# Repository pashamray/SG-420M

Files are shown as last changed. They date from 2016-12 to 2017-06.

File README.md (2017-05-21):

# SG-420M

Прошивка модифицирована для работы с экранами на контроллере [HD44780](https://ru.wikipedia.org/wiki/HD44780), размером 16x2, такими как WH1602.
Подключение экрана аналогично подключению в частотомере [FC-510](http://leoniv.diod.club/projects/measuring/fc-510/fc-510.html)

#### Общий вид генератора

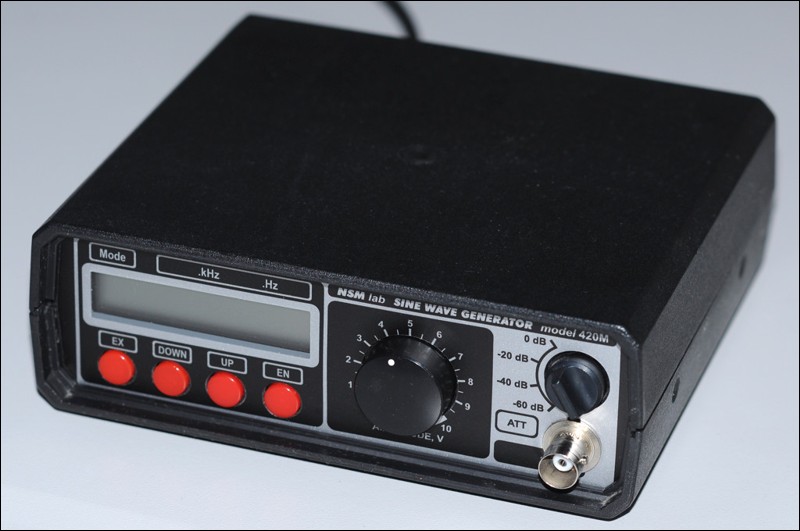
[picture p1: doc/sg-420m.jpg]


#### Вид лицевой панели

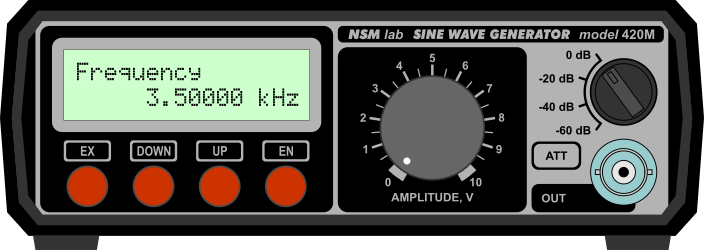
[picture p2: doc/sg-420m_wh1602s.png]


#### Схема подключения экрана

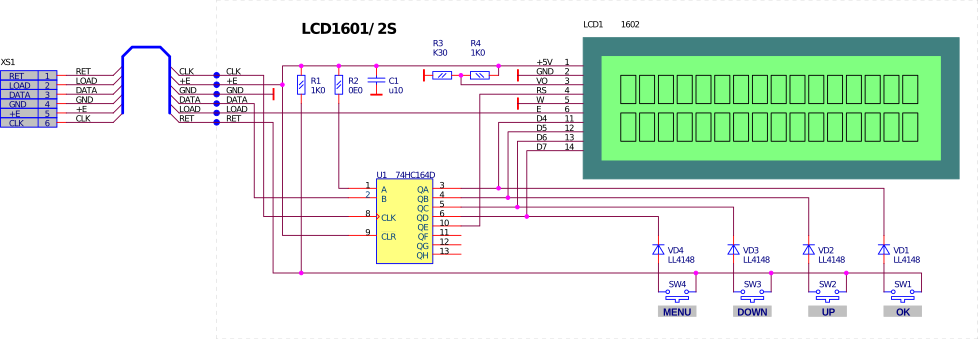
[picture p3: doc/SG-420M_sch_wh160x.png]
alt sch_wh1602s


#### Автор конструкций генератора и базовой прошивки

Ридико Леонид Иванович
* http://www.leoniv.diod.club
* http://leoniv.livejournal.com
* wubblick@yahoo.com

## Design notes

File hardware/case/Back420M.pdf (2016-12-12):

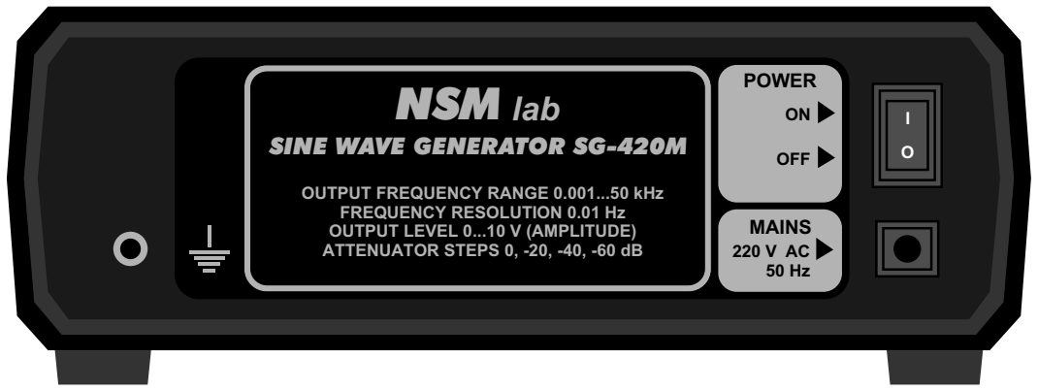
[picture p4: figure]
SINE WAVE GENERATOR SG-420M; NSM lab; OFF; POWER; MAINS; OUTPUT FREQUENCY RANGE 0.001...50 kHz FREQUENCY RESOLUTION 0.01 Hz OUTPUT LEVEL 0...10 V (AMPLITUDE) ATTENUATOR STEPS 0, -20, -40, -60 dB

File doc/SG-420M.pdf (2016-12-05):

NSMlab | wubblick@yahoo.com

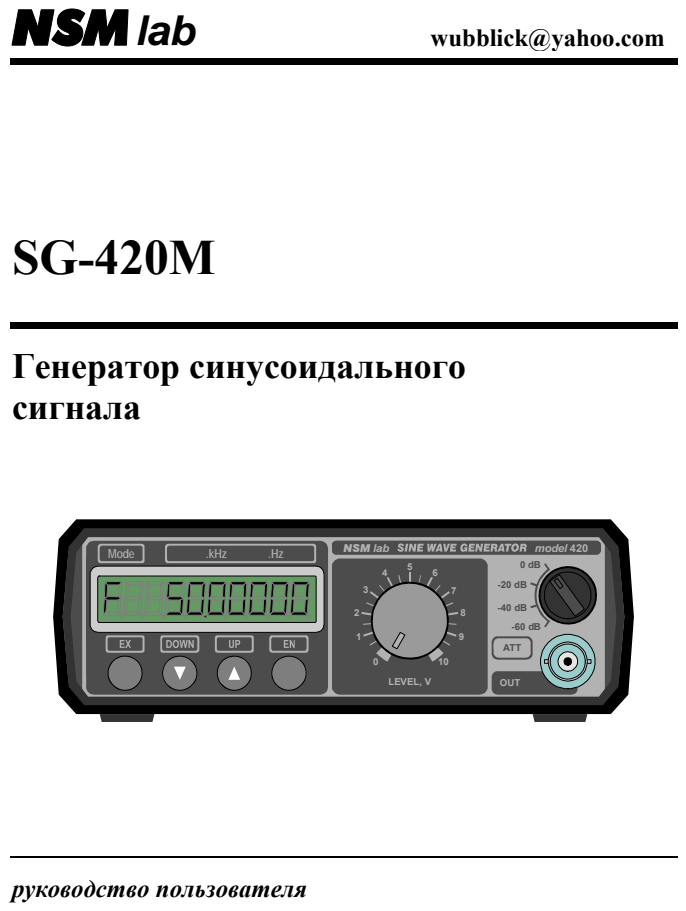
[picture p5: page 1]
Генератор синусоидального сигнала; model 420; OUT; ATT; LEVEL, V; NSM lab Mode; .kHz; руководство пользователя

SG-420M

- 2 -

ОСНОВНЫЕ ХАРАКТЕРИСТИКИ ГЕНЕРАТОРА
- диапазон генерируемых частот – 1…50000 Гц
- минимальный шаг установки частоты – 0.01 Гц
- среднеквадратическое выходное напряжение – 0…10 В
- пределы аттенюатора – 0, -20, -40, -60 дБ
- минимальное сопротивление нагрузки – 600 Ом
- коэффициент гармоник на частоте 1 КГц, не более – 0.01 %
- 10 предустановок частоты
- режим выключения сигнала
- цифровая калибровка частоты
- размеры – 150 x 130 x 50 мм
- вес – 0.4 кг

ОПИСАНИЕ ГЕНЕРАТОРА
Генератор построен на основе прямого цифрового синтезатора частоты (DDS, Direct Digital Synthesizer). Благодаря этому он имеет высокую стабильность выходной частоты, очень малый шаг перестройки и низкий коэффициент гармоник. Кроме того, генератор не имеет аномалий (переходных процессов) при перестройке частоты. Все это, вместе с малыми габаритами и весом, выгодно отличает данный генератор от обычных аналоговых генераторов.
DDS реализован программно на микроконтроллере ATmega8 фирмы "Atmel". Быстродействие этого контроллера является достаточным, чтобы при тактовой частоте 16 МГц реализовать 34-разрядный накопитель фазы, работающий на частоте 216 кГц. Такой накопитель фазы обеспечивает шаг перестройки частоты примерно 0.00001 Гц. Реально используется шаг сетки 0.01 Гц, что более чем достаточно на практике. В памяти микроконтроллера содержится таблица 1/4 периода синусоидального сигнала, адресуемая накопителем фазы. Формирование синусоидального напряжения производится с помощью
16-разрядного | ЦАП | TDA1543 | фирмы | "Philips". | Интерфейс | I²
S | эмулируется
микроконтроллером с помощью аппаратного модуля SPI и таймера. Для полного использования разрешающей способности ЦАП на промежутках между табличными отсчетами производится линейная интерполяция функции sin. Сформированный аналоговый сигнал подвергается низкочастотной фильтрации с помощью фильтра Баттерворта 4-го порядка. Отфильтрованный сигнал поступает на выходной каскад, который обеспечивает работу на нагрузку 600 Ом.
Основные органы управления генератора расположены на передней панели (рис. 1). Там же расположен выходной разъем типа BNC. На задней панели генератора расположены выключатель питания, сетевой шнур и клемма заземления.

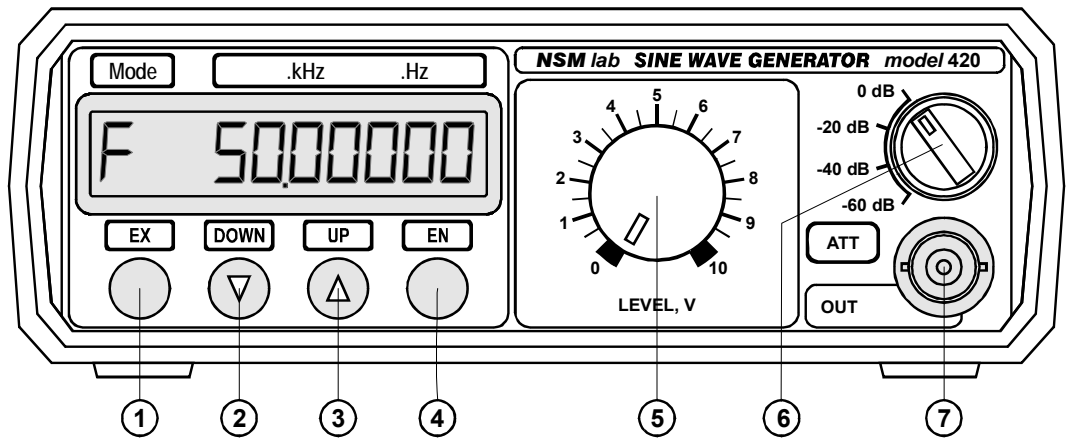
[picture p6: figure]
Mode; NSM lab; model 420; OUT; ATT; LEVEL, V; .kHz
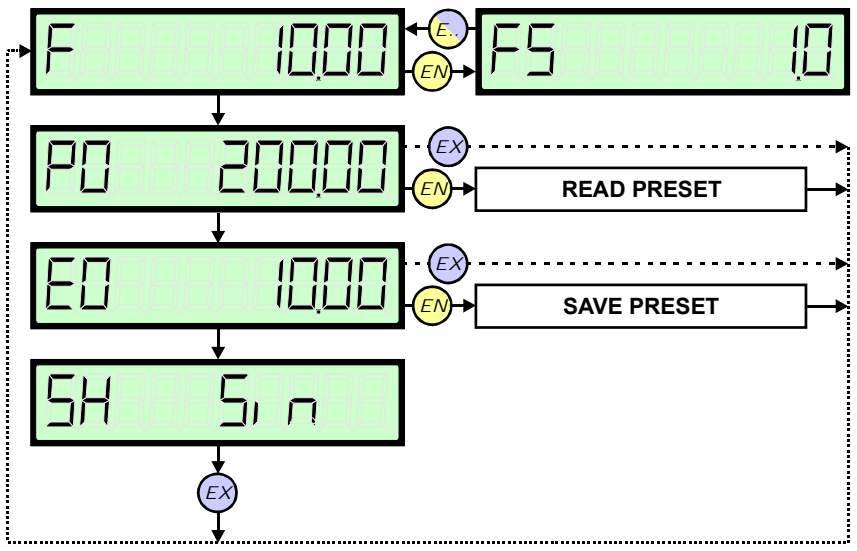
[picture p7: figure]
READ PRESET; SAVE PRESET

- 3 -

Рис. 1. Передняя панель генератора: 1 – кнопка EX (exit, выход); 2 – кнопка DOWN (меньше); 3 – кнопка UP (больше); 4 – кнопка EN (enter, ввод); 5 – ручка регулировки амплитуды выходного сигнала; 6 – ручка аттенюатора; 7 – выходной разъем.

УПРАВЛЕНИЕ ГЕНЕРАТОРОМ
Управление генератором осуществляется с помощью нескольких меню, которые выводятся на ЖКИ. Некоторые меню содержат цифровые значения параметров, другие меню позволяют выбрать нужный режим работы. Система меню организована в виде кольцевой структуры, кнопка EX (Exit) позволяет «по кругу» переходить между меню. Система меню генератора показана на рис. 2.

Рис. 2. Система меню генератора.

С помощью системы меню можно задать частоту выходного сигнала генератора, считать или записать предустановку частоты, а также выключить или включить выходной

- 4 -

сигнал. Увеличение или уменьшение значения выбранного параметра производится кнопками UP или DOWN соответственно. Значение частоты выводится с запятой, которая отделяет десятые доли герца, если значение меньше 1 КГц, или десятые доли килогерца, если значение больше 1 КГц. На рис. 3а показан пример индикации частоты, равной 10 Гц, а на рис. 3б – частоты 10 КГц.

а)

б)

Рис. 3. Пример индикации частоты выходного сигнала: 10 Гц (а) и 10 КГц (б).

Одиночное нажатие кнопки UP или DOWN приводит к изменению частоты на один шаг. Если кнопка продолжает удерживаться более 800 мс, то начинается автоповтор с периодом 180 мс. В таком режиме делается 16 шагов, затем включается быстрый автоповтор с периодом 60 мс.
Шаг изменения значения частоты задается в отдельном меню программирования шага (рис. 4) и может иметь значение 0.01 Гц…10 КГц.

Рис. 4. Меню программирования шага.

Войти в меню программирования шага можно из меню установки выходной частоты с помощью кнопки EN (Enter). Значение шага можно изменять с помощью кнопок UP и DOWN по закону 1-2-5-10-20-50-... и так далее. Выйти из меню программирования шага можно с помощью любой из кнопок EX или EN, при этом формируется специальный звуковой сигнал.
Значение частоты при редактировании с помощью кнопок UP и DOWN выравнивается на значение установленного шага. Например, если величина шага равна 1.00 Гц, текущая частота составляет 120.34 Гц и делается несколько шагов вверх, то получится следующая последовательность: 120.34 Гц, 121.00 Гц, 122.00 Гц и т.д. При перестройке вниз получится: 120.34 Гц, 120.00 Гц, 119.00 Гц и т.д. Поэтому если требуется установить какое-то нецелое значение частоты, нужно начинать с большого шага и заканчивать минимальным. Если текущее значение частоты меньше или равно величины шага, то при нажатии кнопки DOWN происходит автоматическое уменьшение шага по принятому для него закону, при этом раздается звуковой сигнал ошибки и на индикаторе кратковременно отображается то значение шага, которое вызвало ошибку.

- 5 -

ЧТЕНИЕ ПРЕДУСТАНОВОК ЧАСТОТЫ
Меню P (Read Preset) позволяет считать одну из десяти предустановок выходной частоты. При входе в это меню на индикаторе отображается символ P, а справа от него – номер предустановки. Номер может лежать в пределах от 0 до 9. Еще правее на индикаторе отображается значение частоты, сохраненное в данной предустановке. Номер предустановки можно изменять с помощью кнопок UP и DOWN. Чтобы ввести выбранную предустановку, нужно нажать кнопку EN. При этом генератор перестроится на частоту предустановки. Для того, чтобы отменить чтение предустановки, нужно нажать кнопку EX. В этом случае выходная частота останется неизменной, а генератор перейдет в режим установки частоты, если перед этим номер предустановки редактировался, или в меню сохранения предустановок, если номер не редактировался.

СОХРАНЕНИЕ ПРЕДУСТАНОВОК ЧАСТОТЫ
Меню E (Save Preset in EEPROM) позволяет запомнить до десяти значений выходной частоты генератора в виде предустановок. При входе в это меню на индикаторе отображается символ E, а справа от него – номер предустановки. Номер может лежать в пределах от 0 до 9. Еще правее на индикаторе отображается текущее значение выходной частоты генератора. Номер предустановки можно изменять с помощью кнопок UP и DOWN. Чтобы запомнить текущую частоту в выбранной предустановке, нужно нажать кнопку EN. При этом значение частоты сохраняется в EEPROM и формируется специальный звуковой сигнал. Для того, чтобы отменить сохранение предустановки, нужно нажать кнопку EX. В этом случае текущее значение частоты записано в EEPROM не будет, а генератор перейдет в режим установки частоты, если перед этим номер предустановки редактировался, или в меню формы выходного сигнала, если номер не редактировался.

ВЫКЛЮЧЕНИЕ ВЫХОДНОГО СИГНАЛА
Для выключения выходного сигнала генератора служит меню формы выходного сигнала SH (Shape). При входе в это меню на индикаторе отображаются символы SH, а справа от них – вид выходного сигнала. Вид сигнала может быть Sin – сигнал включен и OFF – сигнал выключен (рис. 5). Выключение и включение сигнала происходит с минимальным скачком фазы. Выключение происходит при изменении знака выходного напряжения с минуса на плюс, т.е. при переходе сигнала через ноль. Все время, пока выходной сигнал генератора выключен, на выходе поддерживается нулевое напряжение. При включении выходного синала его формирование начинается с нулевого значения фазы, т.е. с начала положительной полуволны.

а)

б)

Рис. 5. Меню формы выходного сигнала.

- 6 -

НАЧАЛЬНАЯ ЧАСТОТА ГЕНЕРАТОРА
Для того, чтобы при каждом включении питания генератора выходная частота принимала определенное значение, нужно сохранить это значение частоты в предустановке с номером 0. Предустановка 0 также используется для задания частоты, на которой будет производиться калибровка (см. ниже).

ЦИФРОВАЯ КАЛИБРОВКА
Поскольку DDS имеет очень малый шаг перестройки частоты (около 0.002 Гц), а реально используется шаг сетки 0.01 Гц, оказалось возможным осуществить цифровую калибровку частоты. Для калибровки нужно иметь эталонный частотомер или эталонный генератор. В первом случае добиваются нужных показаний частотомера, во втором – равенства частот.
Для осуществления калибровки сначала нужно задать частоту, на которой она будет проводиться. Для этого нужно установить желаемую частоту на выходе генератора и сохранить ее в предустановке с номером 0. Затем нужно войти в меню калибровки. Для этого необходимо выключить питание генератора, а затем включить его снова, удерживая нажатой кнопку EX. При таком включении генератор войдет в специальное меню калибровки. В этом меню на индикаторе отображается символ C и значение калибровочного коэффициента (рис. 6). Калибровочный коэффициент может принимать значения от 0.00 до 999.99. Номинальное значение коэффициента равно 500.00. Изменение значения калибровочного коэффициента на 1.00 соответствует изменению выходной частоты генератора примерно на 1 ppm (одну миллионную часть). Соответственно, с помощью процедуры калибровки можно изменить выходную частоту генератора не более, чем на ±500 ppm. Находясь в меню калибровки значение калибровочного коэффициента можно изменять с помощью кнопок UP и DOWN. Шаг изменения коэффициента равен 10, так как устанавливать выходную частоту до сотых долей ppm не имеет смысла. В процессе калибровки необходимо контролировать выходную частоту генератора, которая меняется при изменении калибровочного коэффициента.

Рис. 6. Меню калибровки.

Когда с помощью изменения значения калибровочного коэффициента требуемая выходная частота достигнута, необходимо сохранить новый калибровочный коэффициент. Для сохранения коэффициента нужно нажать кнопку EN. При этом новый коэффициент запишется в EEPROM, а генератор перейдет в режим установки частоты. Для того, чтобы отменить калибровку, нужно нажать кнопку EX. При этом восстановится прежнее значение калибровочного коэффициента, а генератор перейдет в режим установки частоты.
Если проводить калибровку генератора на частоте 15625.00 Гц, то в качестве эталонной частоты можно использовать строчную частоту телевизионного сигнала, принимаемого с эфира. Точность и стабильность этой частоты вполне достаточна для калибровки. Сравнение частот можно осуществить с помощью осциллографа по фигурам Лиссажу.

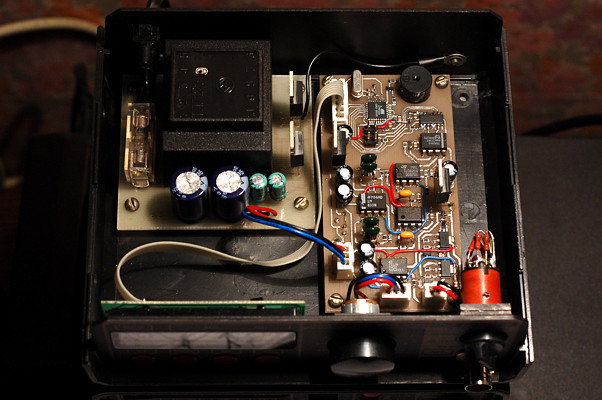
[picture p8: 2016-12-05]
doc/sg-420m_in.jpg

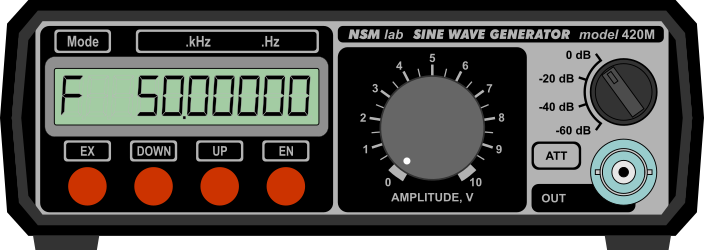
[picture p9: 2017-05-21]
doc/sg-420m_melt7.png

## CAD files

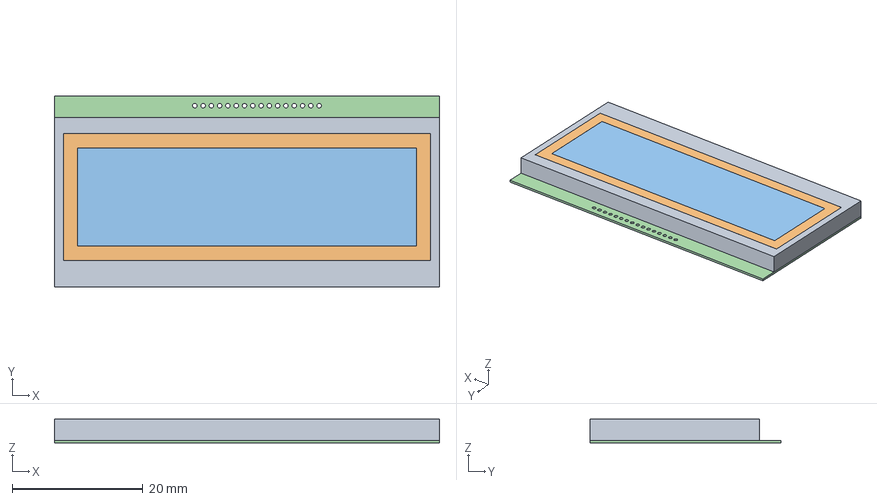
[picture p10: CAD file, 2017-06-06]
hardware/freecad/wh1602s.step
59.0 x 29.3 x 3.65 mm

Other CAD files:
hardware/freecad/wh1602s.fcstd

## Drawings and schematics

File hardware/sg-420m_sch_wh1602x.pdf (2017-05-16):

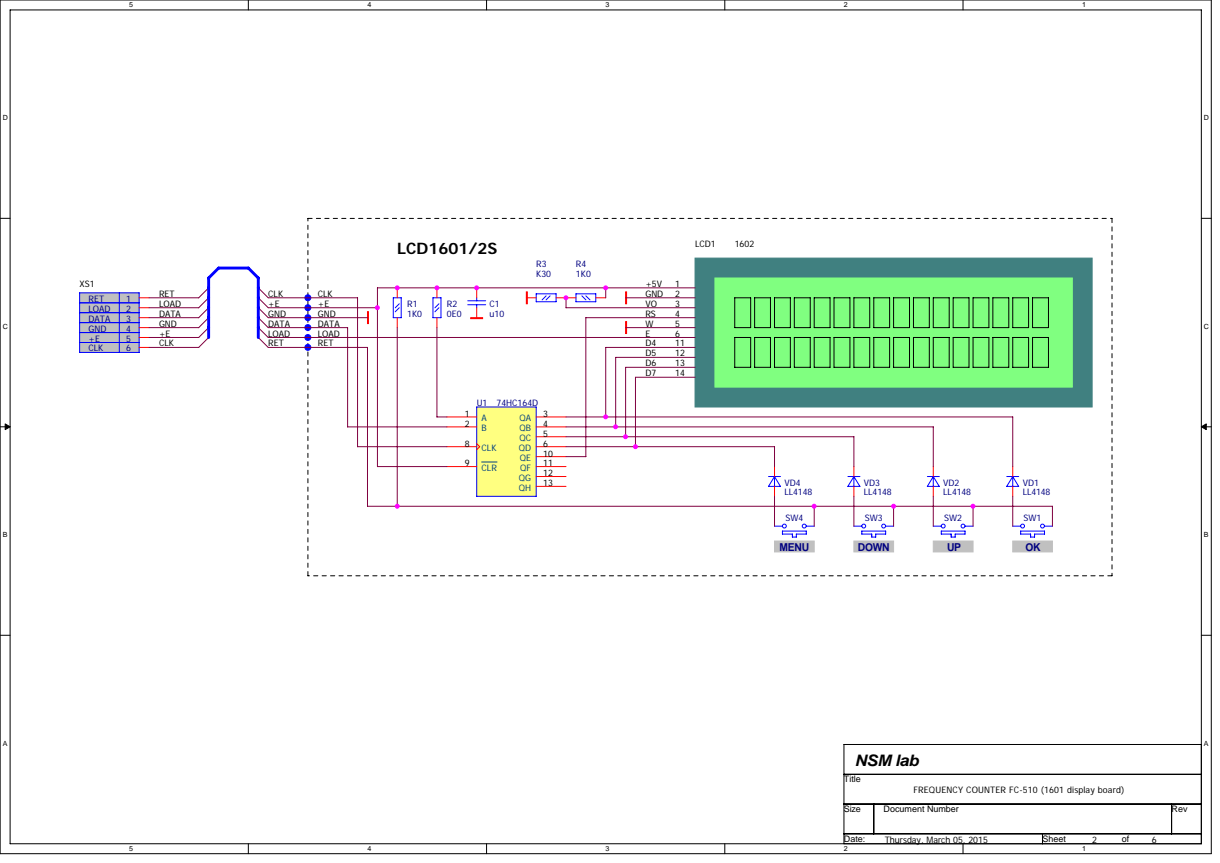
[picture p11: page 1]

RET | 1
LOAD | 2
DATA | 3
GND | 4
+E | 5
CLK | 6

10

FREQUENCY COUNTER FC-510 (1601 display board)

Size | Document Number | Rev

Date: Thursday, March 05, 2015 | Sheet of 2 6

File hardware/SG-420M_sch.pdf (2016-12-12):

# POWER SUPPLY

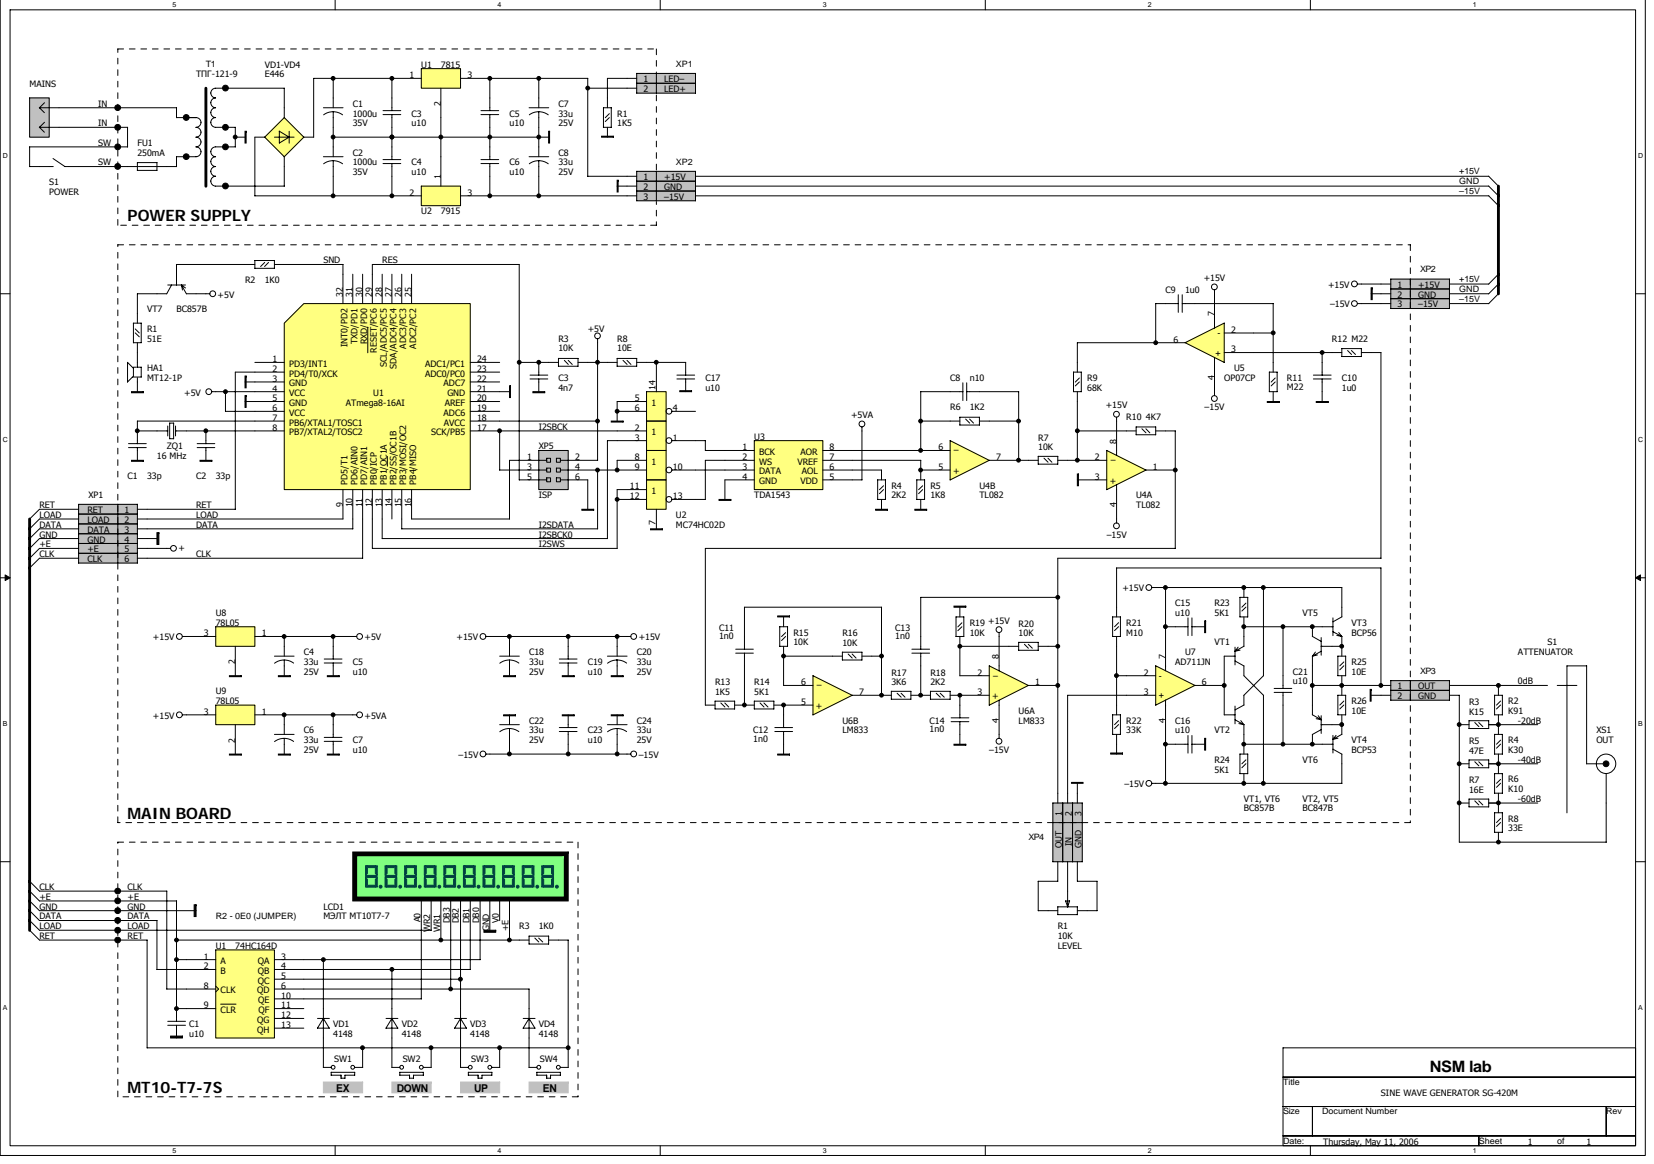
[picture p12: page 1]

1 | LED–
2 | LED+

1 | +15V
2 | GND
3 | –15V

RET | 1
LOAD | 2
DATA | 3
GND | 4
+E | 5
CLK | 6

1 | OUT

SINE WAVE GENERATOR SG-420M

Size | Document Number | Rev

Date: Thursday, May 11, 2006 | Sheet 1 of 1

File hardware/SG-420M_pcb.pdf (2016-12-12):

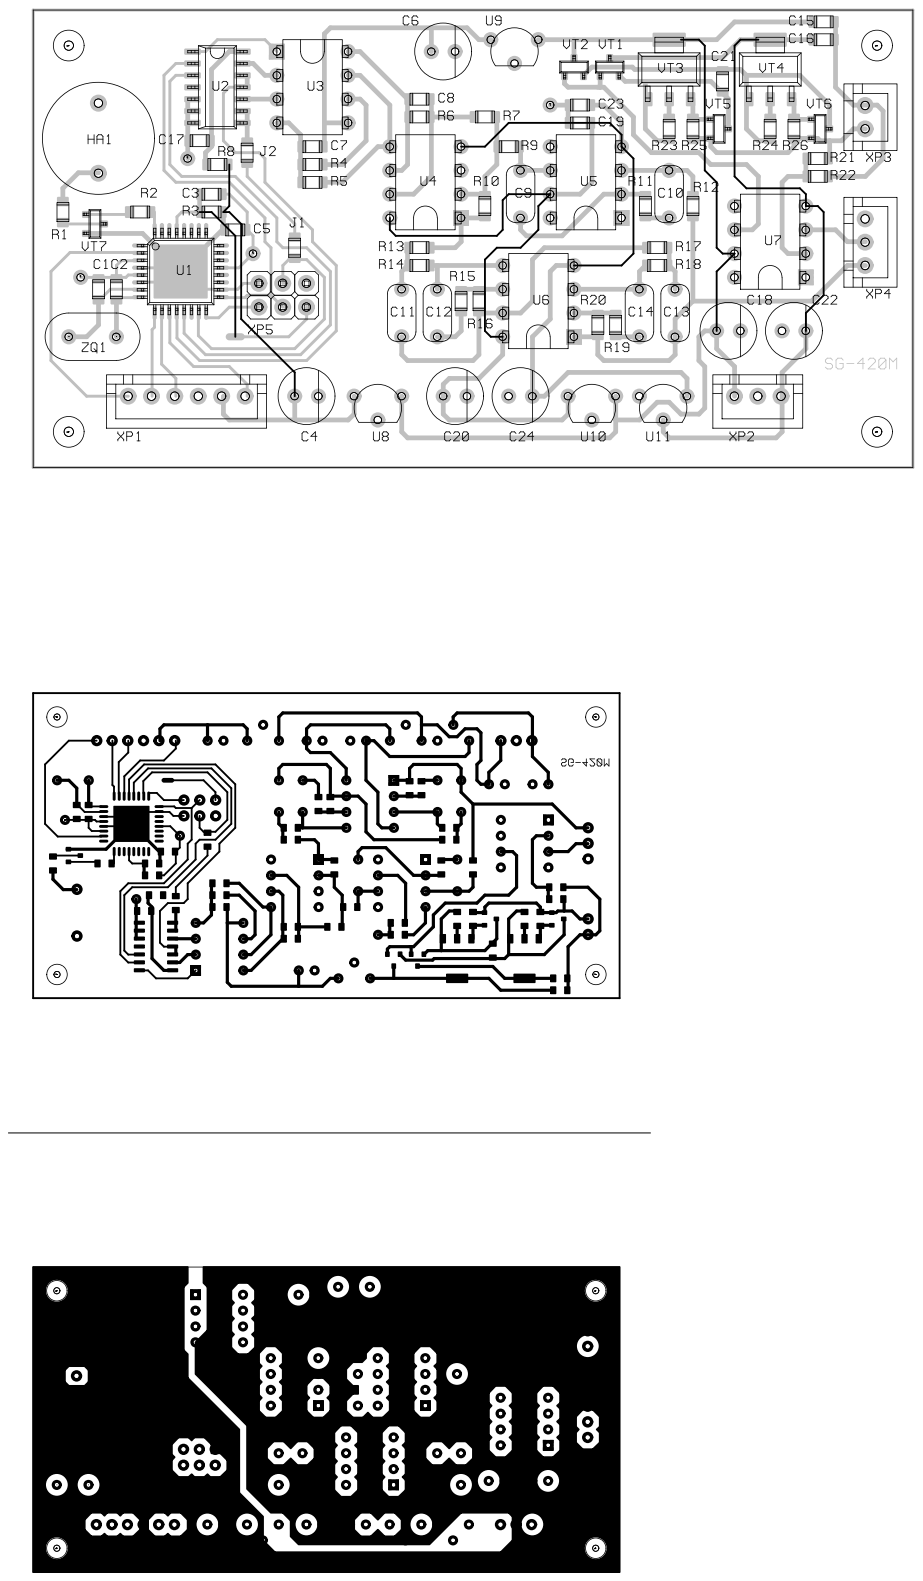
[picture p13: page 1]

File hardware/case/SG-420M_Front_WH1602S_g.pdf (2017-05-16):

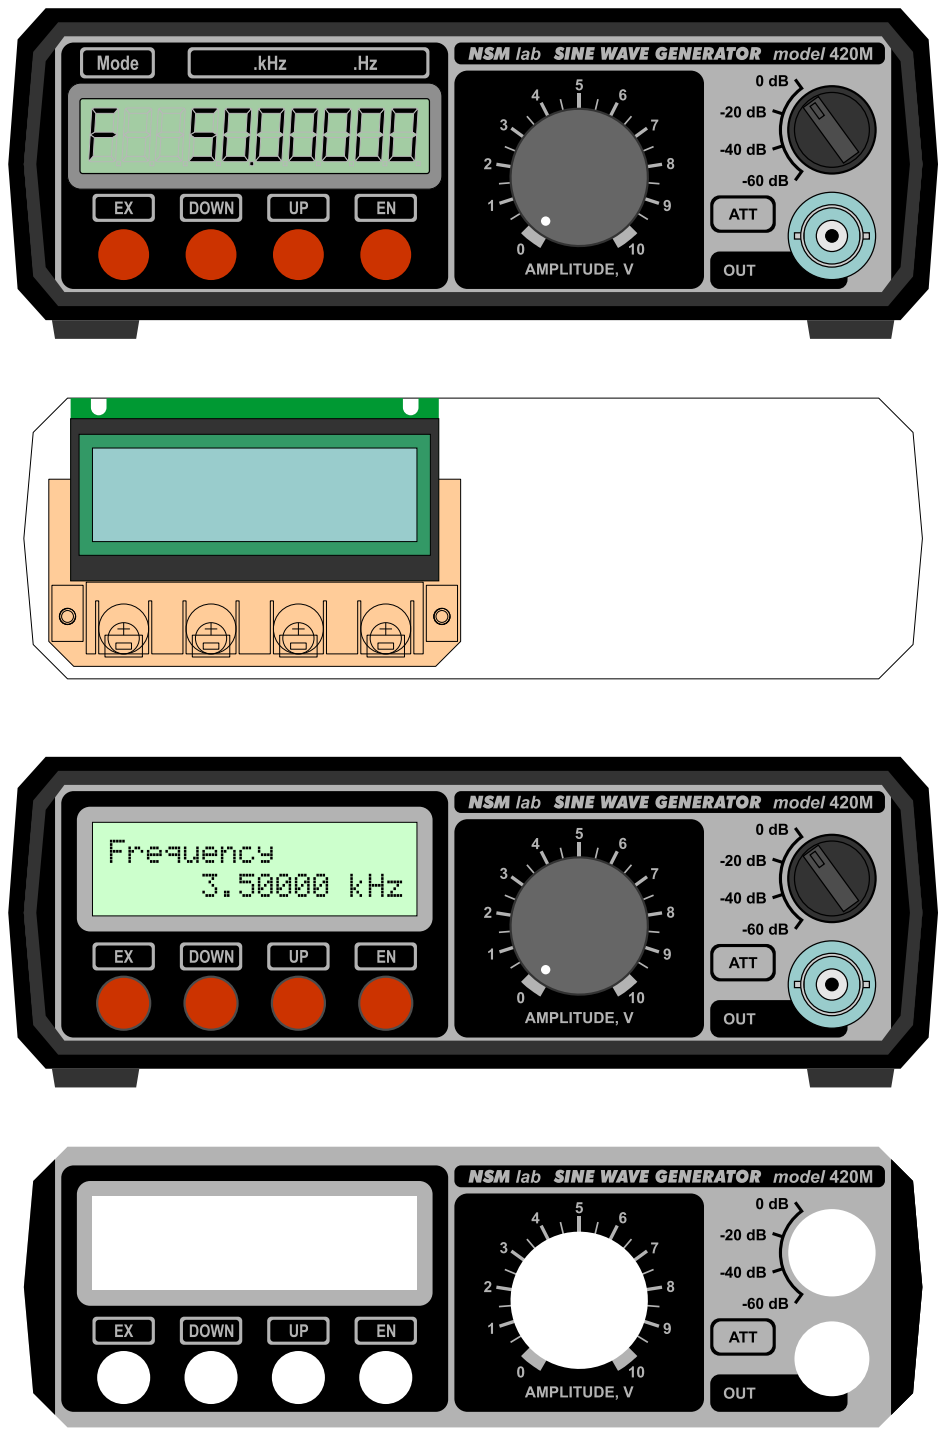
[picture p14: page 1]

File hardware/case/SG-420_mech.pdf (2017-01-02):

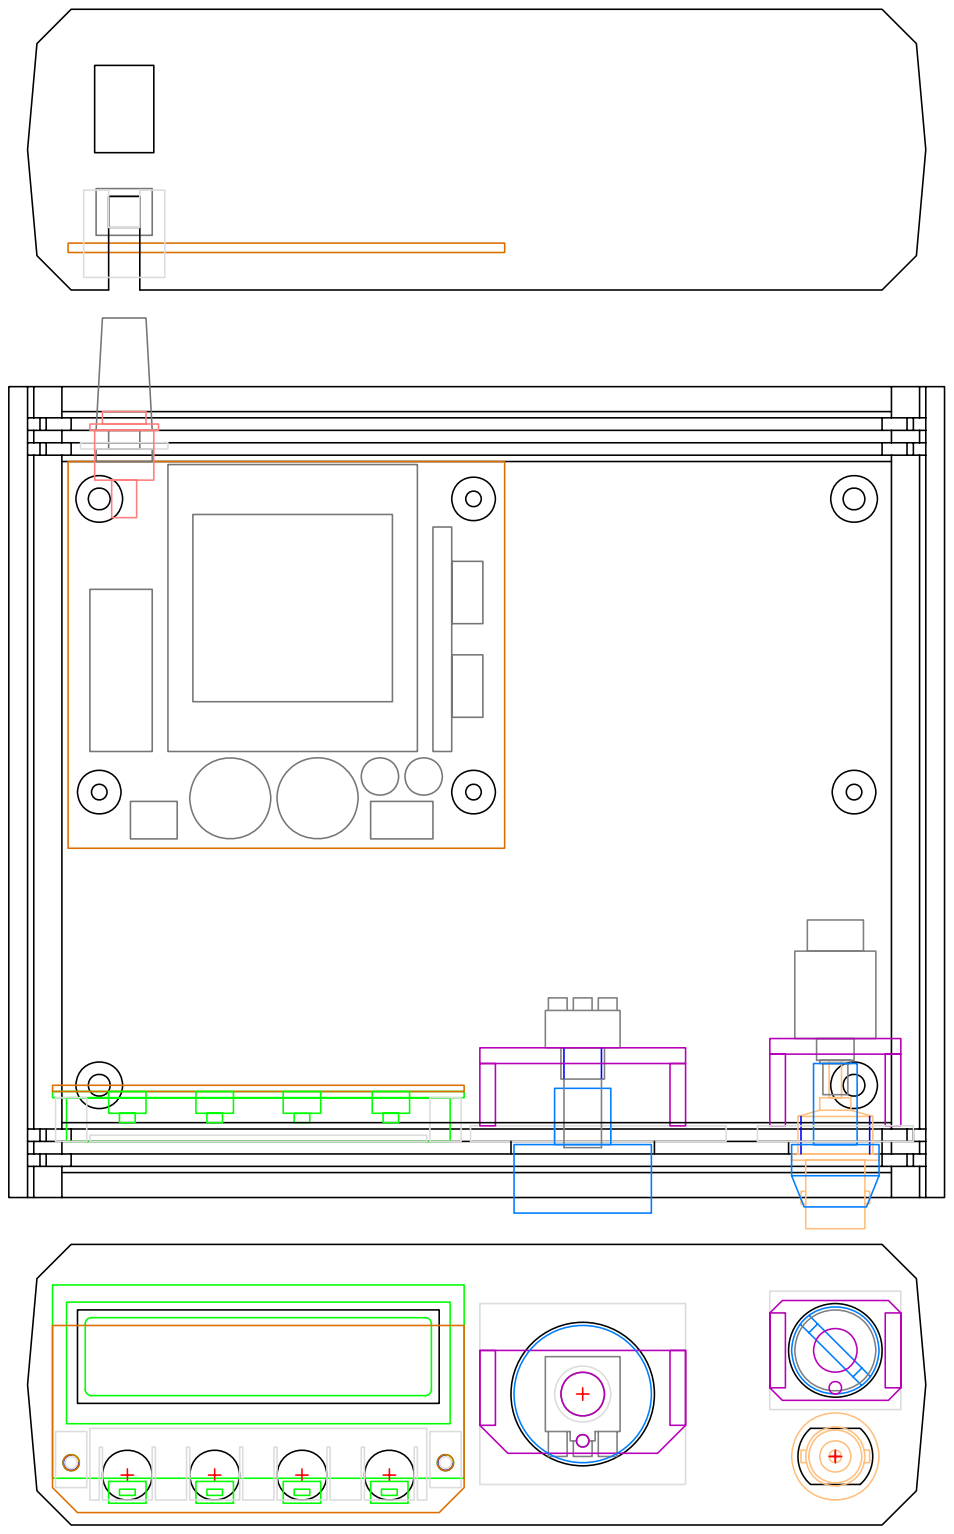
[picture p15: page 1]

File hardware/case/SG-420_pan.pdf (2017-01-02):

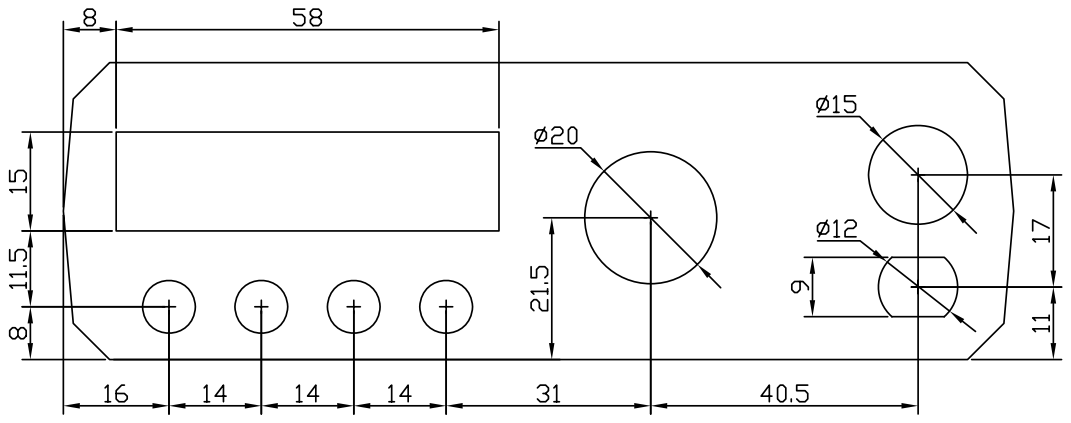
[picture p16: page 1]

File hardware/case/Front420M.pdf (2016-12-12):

# Mode .kHz .Hz

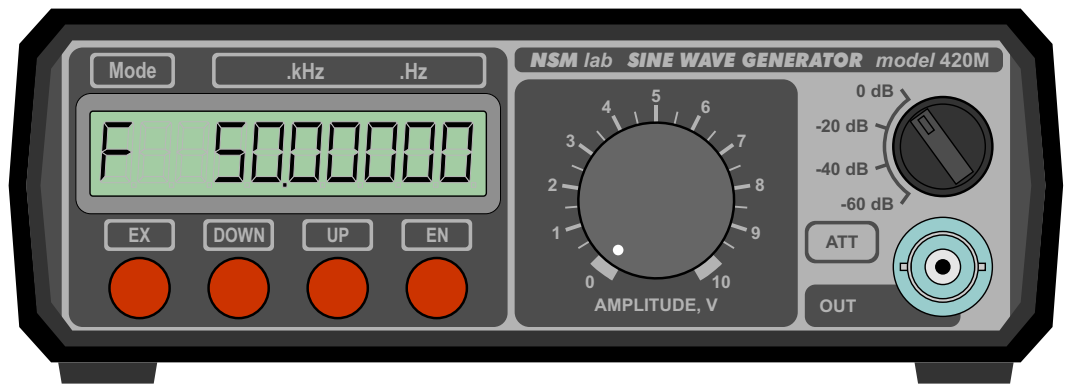
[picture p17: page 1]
DOWN; NSM lab SINE; WAVE GENERATOR model 420M; OUT; ATT; AMPLITUDE, V

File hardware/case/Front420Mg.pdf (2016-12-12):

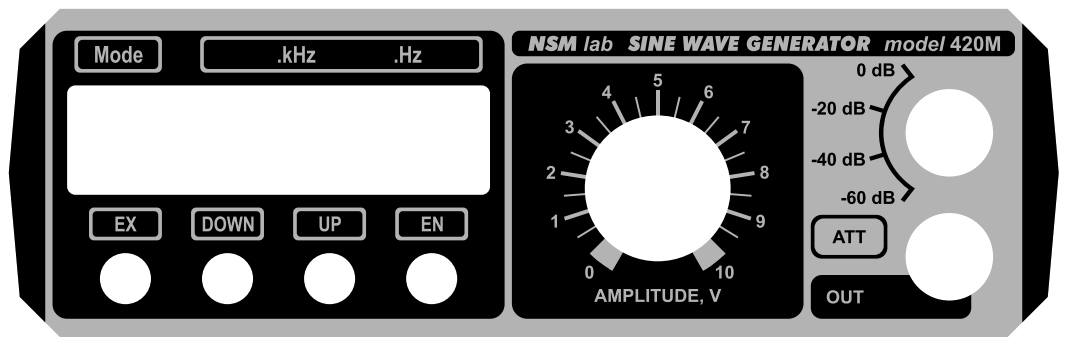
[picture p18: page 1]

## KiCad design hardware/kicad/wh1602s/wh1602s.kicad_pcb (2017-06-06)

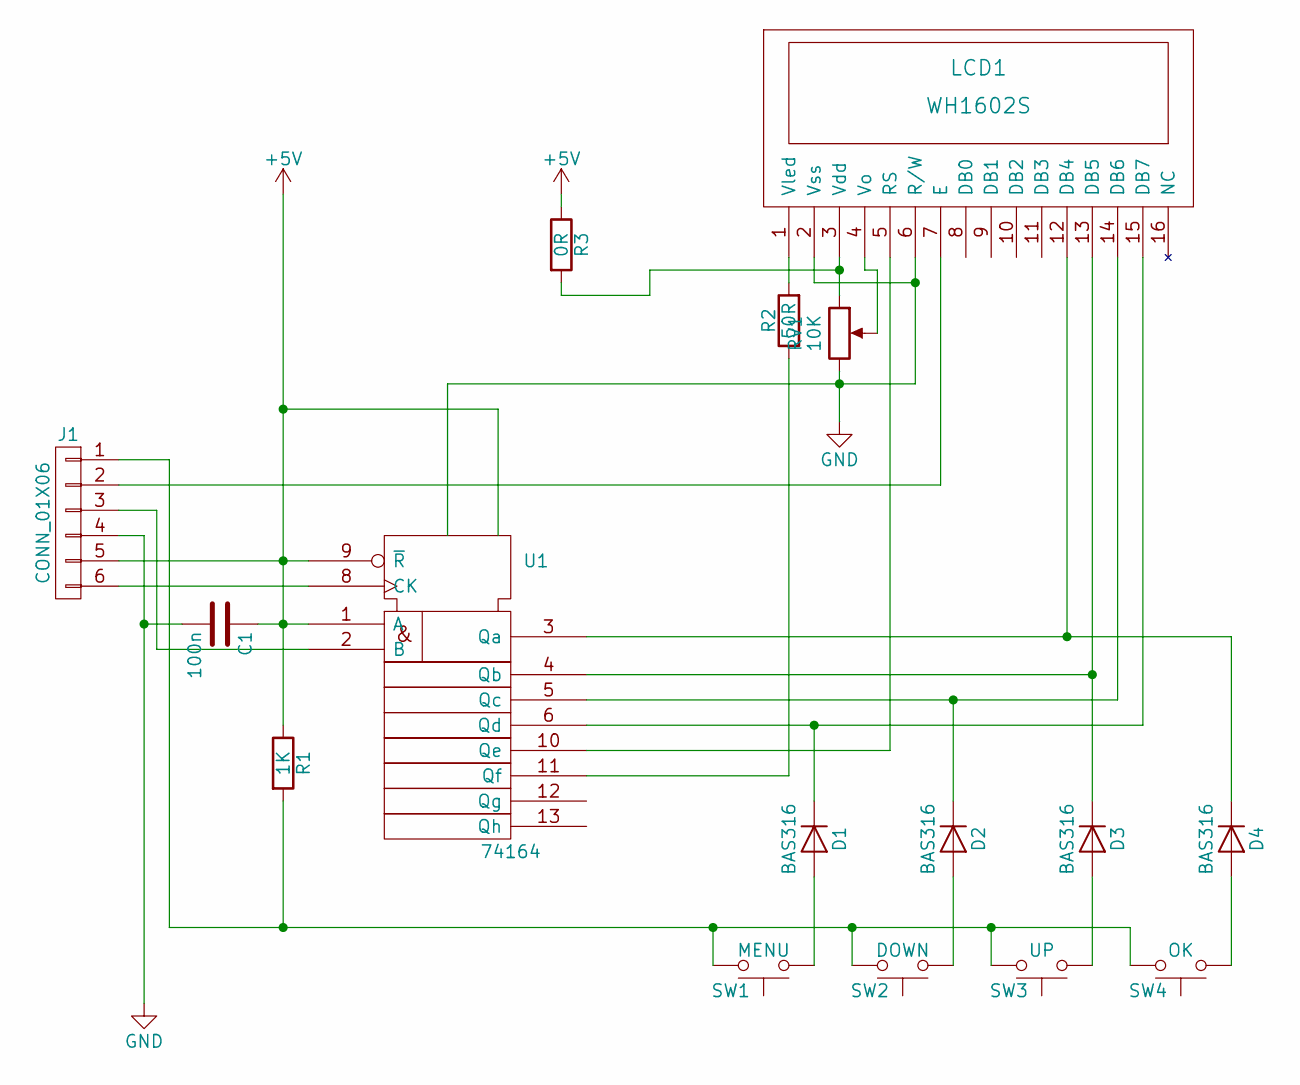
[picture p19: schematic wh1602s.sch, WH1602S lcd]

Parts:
C1: 100n; C_0805
D1, D2, D3, D4: BAS316; D_SOD-323
J1: CONN_01X06; Socket_Strip_Straight_1x06_Pitch2.54mm
LCD1: WH1602S
R1: 1K; R_0805
R2: 50R; R_0805
R3: 0R; R_0805
RV1: 10K; Potentiometer_Trimmer_Bourns_3296W
SW1: MENU; SW_PUSH-12mm
SW2: DOWN; SW_PUSH-12mm
SW3: UP; SW_PUSH-12mm
SW4: OK; SW_PUSH-12mm
U1: 74164; SOIC-14_N

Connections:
+5V: C1.1, J1.5, R1.1, R3.1, U1.1 (A), U1.9 (~R), U1.14 (Vdd)
GND: C1.2, J1.4, LCD1.2 (Vss), LCD1.6 (R/W), RV1.3, U1.7 (Vss)
unnamed: D1.1 (K), LCD1.15 (DB7), U1.6 (Qd)
unnamed: D1.2 (A), SW1.1
unnamed: D2.1 (K), LCD1.14 (DB6), U1.5 (Qc)
unnamed: D2.2 (A), SW2.1
unnamed: D3.1 (K), LCD1.13 (DB5), U1.4 (Qb)
unnamed: D3.2 (A), SW3.1
unnamed: D4.1 (K), LCD1.12 (DB4), U1.3 (Qa)
unnamed: D4.2 (A), SW4.1
unnamed: J1.1, R1.2, SW1.2, SW2.2, SW3.2, SW4.2
unnamed: J1.2, LCD1.7 (E)
unnamed: J1.3, U1.2 (B)
unnamed: J1.6, U1.8 (CK)
unnamed: LCD1.1 (Vled), R2.2
unnamed: LCD1.3 (Vdd), R3.2, RV1.1
unnamed: LCD1.4 (Vo), RV1.2
unnamed: LCD1.5 (RS), U1.10 (Qe)
unnamed: R2.1, U1.11 (Qf)

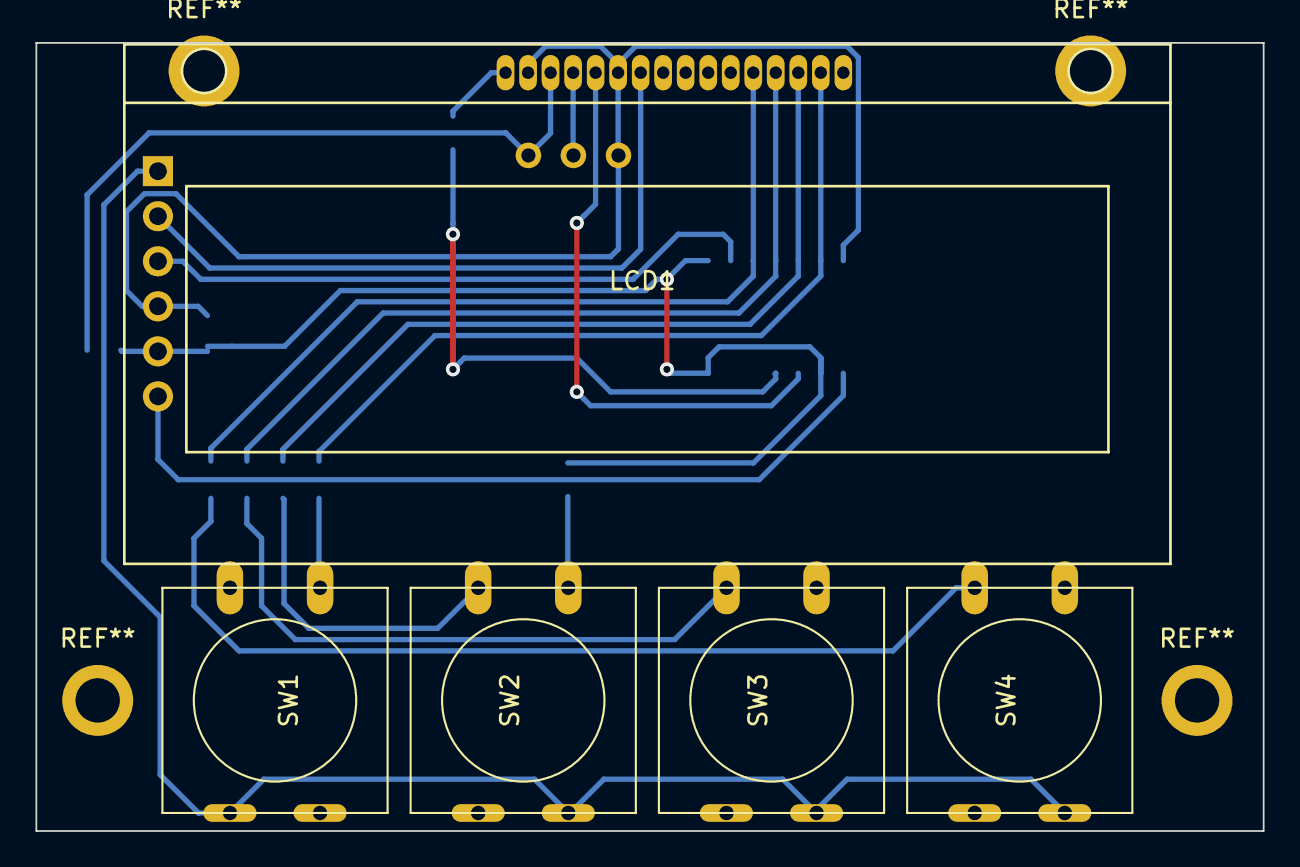
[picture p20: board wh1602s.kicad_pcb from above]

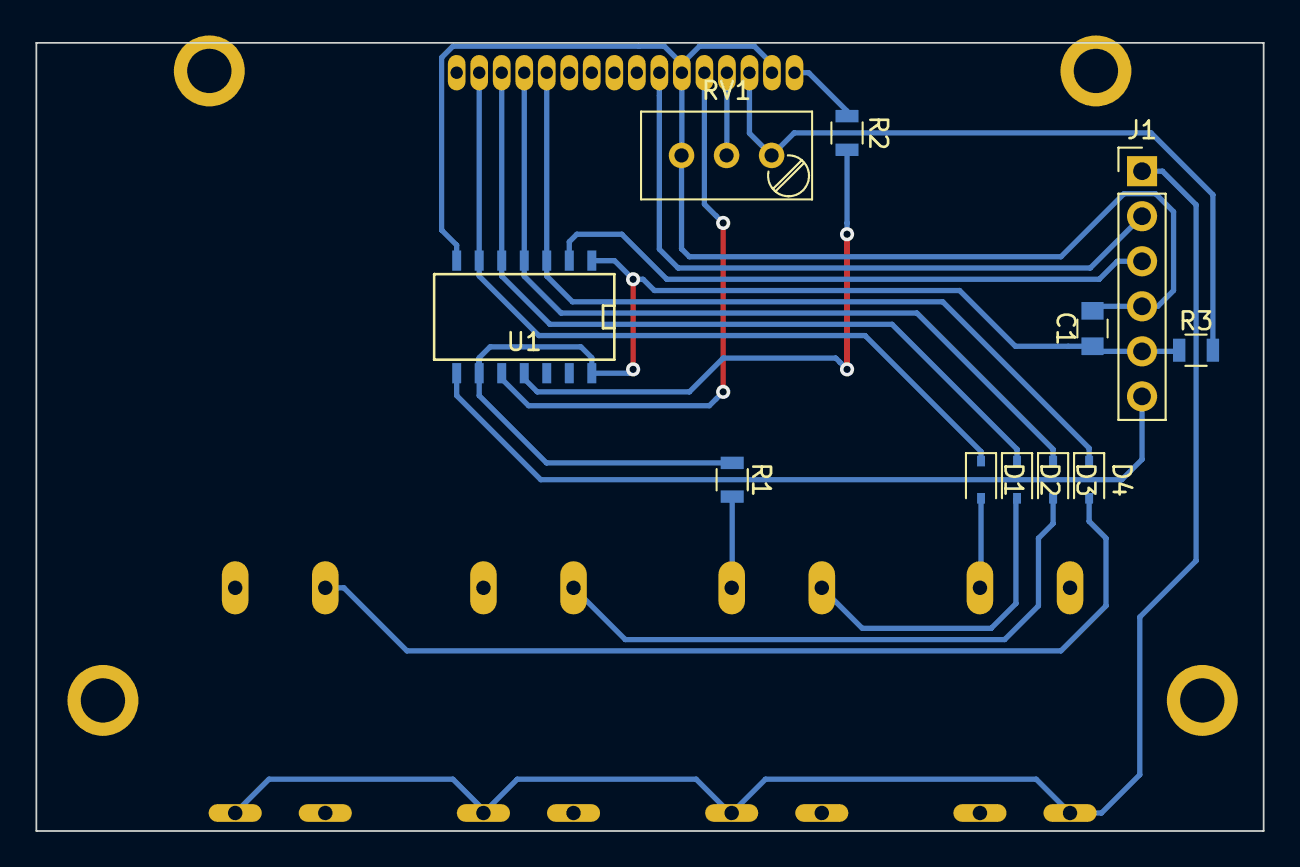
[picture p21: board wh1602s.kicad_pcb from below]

Board: 2 copper layers, 69.2 x 44.5 mm, 16 parts (11 on the bottom side), 19 nets.

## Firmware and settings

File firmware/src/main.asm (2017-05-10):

;----------------------------------------------------------------------------

;* Title	: SG-420M sine wave generator
;* Version	: 1.00
;* Target	: ATmega8
;* Author	: wubblick@yahoo.com

;----------------------------------------------------------------------------

.include "m8def.inc"
.include "macros.inc"
.include "header.asm"

;------------------------- Interrupt Vectors: -------------------------------

.CSEG				;code segment
.org	0
	rjmp	Init		;reset vector

.org	OC1Aaddr
.include "dds.asm"			;link DDS implementation module
							;DDS implementation is located direct at the OC1A vector address
							;Only one interrupt is used in this project

;--------------------------- Main program: ----------------------------------

Init:
	ldy		RAMEND
	out		SPL,YL		;locate stack
	out		SPH,YH
	rcall	iWdog		;start internal watchdog
	rcall	iPorts		;ports init
	rcall	iVar		;variables init
	rcall	iTimer		;system timer init
	rcall	iDisp		;LCD init
	rcall	iDDS		;DDS subsystem init
	sei					;enable interrupts
	rcall	iMenu		;menu subsystem init

;Main loop:

Main:
	rcall	mTimer		;process system timer
	rcall	mKey		;scan keyboard
	rcall	mMenu		;process menu
	rcall	mDisp		;update display
	rcall	mOn			;process ON bit
	rcall	mWdog		;watchdog restart
	rjmp 	Main		;loop

;------------------------- Subroutines area: --------------------------------

;Internal watchdog init:

iWdog:
	wdr
	ldi		temp,(1<<WDCE) | (1<<WDE)
	out		WDTCR,temp
	ldi		temp,(1<<WDE) | (1<<WDP2)
	out		WDTCR,temp	;watchdog enable, period 260 mS
	ret

;----------------------------------------------------------------------------

;Internal watchdog restart:

mWdog:
	wdr			;internal watchdog restart
	ret

;----------------------------------------------------------------------------

;System timer init:

iTimer:
	ldi		temp,(1<<CS02) | (1<<CS00)
	out		TCCR0,temp	;CK/1024
	ret

;----------------------------------------------------------------------------

;Process system timer:

mTimer:
	clbr	Flags,UPD
	in		temp,TIFR
	bbrc	temp,TOV0,no_tm	;check for Timer 0 overflow
	stbr	temp,TOV0	;Timer 0 overflow flag clear
	out		TIFR,temp
	ldi		temp,T0Val
	out		TCNT0,temp	;Timer 0 reload
	stbr	Flags,UPD	;set update flag
no_tm:
	ret

;----------------------------------------------------------------------------

;Ports init:

iPorts:
	ldi		temp,PUPB
	out		PORTB,temp	;init PORTB and on/off pullup
	ldi		temp,DIRB
	out		DDRB,temp	;set PORTB direction

	ldi		temp,PUPC
	out		PORTC,temp	;init PORTC and on/off pullup
	ldi		temp,DIRC
	out		DDRC,temp	;set PORTC direction

	ldi		temp,PUPD
	out		PORTD,temp	;init PORTD and on/off pullup
	ldi		temp,DIRD
	out		DDRD,temp	;set PORTD direction
	ret

;----------------------------------------------------------------------------

;Variables init:

iVar:
	clr		Flags		;clear flags
	ret

;----------------------------------------------------------------------------

.include "lcd_1602.asm"		;link LCD support module
.include "keyboard.asm"		;link keyboard support module
.include "beeper.asm"		;link beeper support module
.include "menu_1602.asm"	;link menu implementation module
.include "eeprom.asm"		;link EEPROM support module

;----------------------------------------------------------------------------

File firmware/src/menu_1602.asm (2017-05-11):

;----------------------------------------------------------------------------

;Menu implementation module

;----------------------------------------------------------------------------

;Constantes:

.equ	MIN_F	= 100		;F min,  x0.01 Hz
.equ	MAX_F	= 5000000	;F max,  x0.01 Hz
.equ	MIN_FS	= 1			;FS min, x0.01 Hz
.equ	MAX_FS	= 1000000	;FS max, x0.01 Hz
.equ	MIN_SH	= 0			;min SH menu index
.equ	MAX_SH	= 1			;max SH menu index
.equ	MIN_PE	= 0			;min P and E menus index
.equ	MAX_PE	= 9			;max P and E menus index
.equ	MIN_C	= 0			;min calibration value
.equ	MAX_C	= 99999		;max calibration value
.equ	STEP_C	= 10		;calibration value edit step
.equ	C_0		= 50000		;nominal calibration value C

;Menu structure and codes:

;[F  0]	<-> [FS 4]
;  |
;[P  1]
;  |
;[E  2]
;  |
;[SH 3]
;
;[C  5]

.equ	MnuF	=0		;edit Frequency
.equ	MnuP	=1		;read Preset
.equ	MnuE	=2		;preset save in Eeprom
.equ	MnuSH	=3		;set Shape
.equ	MnuFS	=4		;edit Frequency Step
.equ	MnuC	=5		;calibration

;----------------------------------------------------------------------------

;Variables:

.DSEG	;data segment (internal RAM)

Menu:	.byte 1			;menu code

Calib:	.byte 3			;calibration
ValFS:	.byte 3			;frequency step
ValF:	.byte 3			;frequency
ValP:	.byte 3			;preset

Buff:	.byte 3			;edit buffer
Step:	.byte 3			;plus/minus step
Max:	.byte 3			;max limit
Min:	.byte 3			;min limit

;----------------------------------------------------------------------------

;Macros:

.macro	ldmi			;load tempH,M,L with 24-bit data
	ldi 	tempL,byte1(@0)
	ldi 	tempM,byte2(@0)
	ldi 	tempH,byte3(@0)
.endm

.macro	ldei			;load tempF,E,D with 24-bit data
	ldi 	tempD,byte1(@0)
	ldi 	tempE,byte2(@0)
	ldi 	tempF,byte3(@0)
.endm

;----------------------------------------------------------------------------

.CSEG	;Code segment

;----------------------------------------------------------------------------

;Init menu subsystem:

iMenu:
	ldi		Flags,(1<<ON) | (1<<ONR) | (1<<UPDD)
	rcall	ReadF		;read from EEPROM Calib, ValFS, ValF
	ldi		temp,MnuF	;menu "Frequency"
	sts		Menu,temp
	rcall	SetMd		;set mode, calculate Freq and enable interrupts
	rcall	Update		;update display data

	rcall	Scan
	cpi		temp,K_EX	;EX pressed ?
	brne	norm
	ldi		temp,MnuC	;menu "Calibration"
	sts		Menu,temp
	rcall	SetMd		;set calibration mode
	rcall	Update		;update display data
	rcall	Disp		;display

norm:
	ldi		tempE,35
	rcall	Tone		;initial beep

rels:
	rcall	Scan
	wdr
	cpi		temp,K_NO
	brne	rels		;wait for keyboard release
	ret

;----------------------------------------------------------------------------

;Process key functions:

mMenu:	bbrc	Flags,NEWPR,NoPr
	ldy	KBD
	ldd	temp,Y+Lc	;temp <- LastCode
	cpi	temp,K_NO
	breq	NoPr		;skip if no press
	rcall	Sound		;key beep
	cpi	temp,K_UP
	brne	Pro1
	rcall	Do_UP		;key UP processing
	rjmp	NoPr
Pro1:	cpi	temp,K_DN
	brne	Pro2
	rcall	Do_DN		;key DN processing
	rjmp	NoPr
Pro2:	cpi	temp,K_EX
	brne	Pro3
	rcall	Do_EX		;key EX processing
	rjmp	NoPr
Pro3:	cpi	temp,K_EN
	brne	NoPr
	rcall	Do_EN		;key EN procesing
NoPr:	ret

;----------------------------------------------------------------------------

;Key "UP" processing:

Do_UP:	lds	temp,Menu
	cpi	temp,MnuFS	;---> menu "Frequency Step"?
	breq	upst

;Buff + Step, align value to step

	ldy		Buff
	rcall	LdLMH		;tempH:tempM:tempL = Buff
	ldy	Step
	rcall	LdDEF		;tempF:tempE:tempD = Step
	rcall	div24		;tempC:tempB:tempA = Rem(Buff / Step)
	ldy	Buff
	rcall	LdLMH		;tempH:tempM:tempL = Buff
	sub	tempL,tempA	;tempH:tempM:tempL - Rem(Buff / Step)
	sbc	tempM,tempB
	sbc	tempH,tempC
	add	tempL,tempD	;tempH:tempM:tempL + Step
	adc	tempM,tempE
	adc	tempH,tempF
	rjmp	upv		;validate buffer

;Step change (1 -> 2 -> 5 -> 10 -> 20..)

upst:	ldy	Buff
	rcall	LdLMH		;tempH:tempM:tempL = Buff
	lsl	tempL
	rol	tempM
	rol	tempH		;Buff * 2
	rcall	Search
	cpi	temp,2
	brne	upv		;validate buffer
	ldy	Buff
	rcall	LdABC		;tempC:tempB:tempA = Buff
	lsr	tempC
	ror	tempB
	ror	tempA		;Buff / 2
	add	tempL,tempA
	adc	tempM,tempB
	adc	tempH,tempC	;Buff * 2.5

upv:	rcall	Valid		;validate tempH:tempM:tempL
	rcall	Assume		;assume new parameters
	stbr	Flags,EDT	;set edited flag
	rcall	Update		;update display data
	ret

;----------------------------------------------------------------------------

;Key "DN" processing:

Do_DN:	lds	temp,Menu
	cpi	temp,MnuFS	;---> menu "Frequency Step"?
	breq	dnst


;Buff - Step, align value to step

	ldy	Buff
	rcall	LdLMH		;tempH:tempM:tempL = Buff
	ldy	Step
	rcall	LdDEF		;tempF:tempE:tempD = Step
	rcall	div24		;tempC:tempB:tempA = Rem(Buff / Step)
	ldy	Buff
	rcall	LdLMH		;tempH:tempM:tempL = Buff
	mov	temp,tempA
	or	temp,tempB
	or	temp,tempC
	breq	dn0
	sub	tempL,tempA	;Buff - Rem(Buff/Step)
	sbc	tempM,tempB
	sbc	tempH,tempC
	rjmp	dnv		;validate buffer
dn0:	sub	tempL,tempD	;Buff - Step
	sbc	tempM,tempE
	sbc	tempH,tempF
dn1:	rjmp	dnv		;validate buffer

;Step change (..20 -> 10 -> 5 -> 2 -> 1)

dnst:	ldy	Buff
	rcall	LdLMH		;tempH:tempM:tempL = Buff
	lsr	tempH
	ror	tempM
	ror	tempL		;Buff / 2
	rcall	Search
	cpi	temp,5
	brne	dnv		;validate buffer
	ldy	Buff
	rcall	LdLMH		;tempH:tempM:tempL = Buff
	lsl	tempL
	rol	tempM
	rol	tempH		;Buff * 2
	ldi	tempD,5
	clr	tempE
	clr	tempF
	rcall	Div24		;Buff / 2.5

dnv:	rcall	Valid		;validate tempH:tempM:tempL
	rcall	Assume		;assume new parameters
	stbr	Flags,EDT	;set edited flag
	rcall	Update		;update display data
	ret

;----------------------------------------------------------------------------

;Key "EX" processing (change menu item):

Do_EX:	lds	temp,Menu
	cpi	temp,MnuFS	;---> menu "Frequency Step":
	breq	Do_EN		;process enter key

	cpi	temp,MnuC	;---> menu "Calibration":
	brne	ex1
	rcall	ReadF		;skip calibration, read Calib from EEPROM
	rjmp	exf		;return to the frequency menu

ex1:	cpi	temp,MnuF	;---> menu "Frequency":
	breq	exn

	bbrc	Flags,EDT,ex2	;if (EDT == 1) return to the frequency menu
	rjmp	exf		;else next menu item

ex2:	cpi	temp,MnuSH	;---> menu "Shape":
	breq	exf		;return to the frequency menu

exn:	inc	temp		;next menu item
	rjmp	ex0
exf:	ldi	temp,MnuF
ex0:	sts	Menu,temp
	rcall	SetMd		;set mode
	rcall	Update		;update display data
	ret

;----------------------------------------------------------------------------

;Key "EN" processing (change menu item):

Do_EN:
	lds		temp,Menu
	cpi		temp,MnuC	;---> menu "Calibration":
	brne	en1
	rcall	SaveC		;save Calib in EEPROM
	rjmp	enf			;return to the frequency menu

en1:
	cpi		temp,MnuF	;---> menu "Frequency":
	brne	en2
	ldi		temp,MnuFS	;jump to the frequency step menu
	rjmp	en0

en2:
	cpi		temp,MnuP	;---> menu "Read Preset":
	brne	en3
	ldy		ValP
	rcall	LdLMH		;tempH:tempM:tempL = ValP
	ldy		ValF
	rcall	StLMH		;ValF = tempH:tempM:tempL
	rjmp	ens			;beep and return to the frequency menu

en3:
	cpi		temp,MnuE	;---> menu "Save Preset":
	brne	en4
	rcall	SaveP		;save preset
	rjmp	enf			;return to the frequency menu

en4:
	cpi		temp,MnuSH	;---> menu "Shape":
	brne	ens			;beep and return to the frequency menu
	rcall	ErrB		;error beep
	rjmp	enx
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

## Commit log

2016-12-14 add case doc
2017-01-10 add sources refactor
    [sg-420m.obj]
2017-01-10 add macros.mac edit build file
    [sg-420m.obj]
2017-01-11 add LCD_1602.asm comment output block code for simulate add proteus simulate file edit build script
    [sg-420m.DSN, sg-420m.obj]
2017-01-11 add wait.asm
    [sg-420m.DSN, sg-420m.obj]
2017-01-11 run testing init
    [sg-420m.obj]
2017-01-11 fix data out swap
    [sg-420m.obj]
2017-01-11 fix data out
    [sg-420m.DSN, sg-420m.obj]
2017-01-12 fix Init
    [sg-420m.DSN, sg-420m.obj]
2017-01-12 del proteus files fix data out
    [sg-420m.DSN, sg-420m.obj]
2017-01-13 add nop timing to init
    [sg-420m.DSN, sg-420m.obj]
2017-01-15 edit for proteus
    [sg-420m.obj]
2017-01-16 out first line
    [sg-420m.obj]
2017-01-17 refactor add strings
    [sg-420m.obj]
2017-01-18 out 1 line Frequency, 2 line kHz
    [sg-420m.DSN, sg-420m.obj]
2017-05-16 del proteus files
    [sg-420m.DSN]
2017-06-06 add freecad wh1602s model files add kicad wh1602s pcb files
    [sg-420m.sch, wh1602s.fcstd, wh1602s.kicad_pcb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]
